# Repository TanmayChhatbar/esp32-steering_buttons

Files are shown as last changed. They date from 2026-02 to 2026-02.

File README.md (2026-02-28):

# ESP32 Steering Buttons

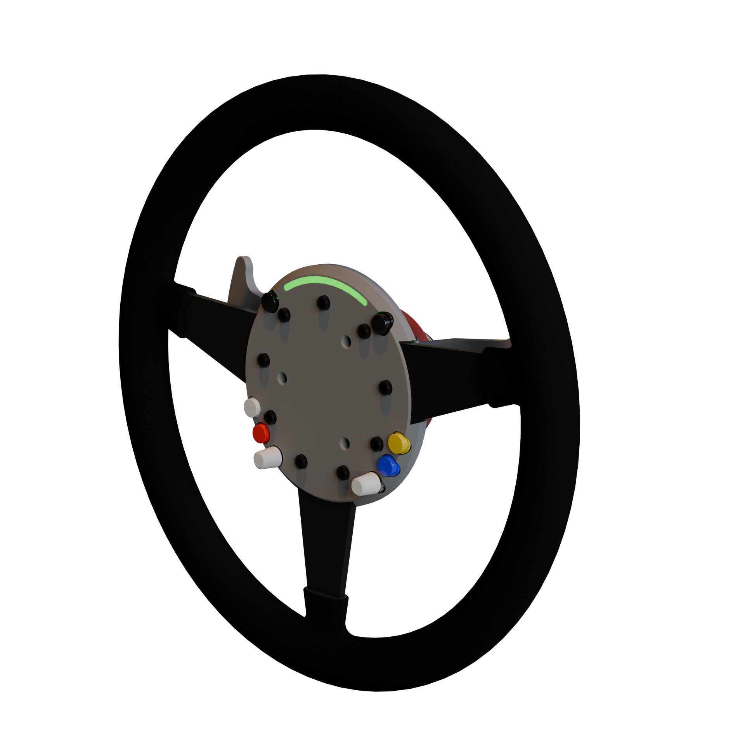
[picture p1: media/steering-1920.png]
Demo Video


## What you will need

- A steering wheel
- A few buttons
- A few encoders
- ESP32-S3 Supermini
- Simagic QR70 Quick-release (I use this for powering the ESP32 on the board)

## Notes

This repository is more a demo than a guide for DIY wheel buttons for an ESP32.

It uses the lemmingdev/ESP32-BLE-Gamepad library to handle the joystick control component.

LED is WIP.

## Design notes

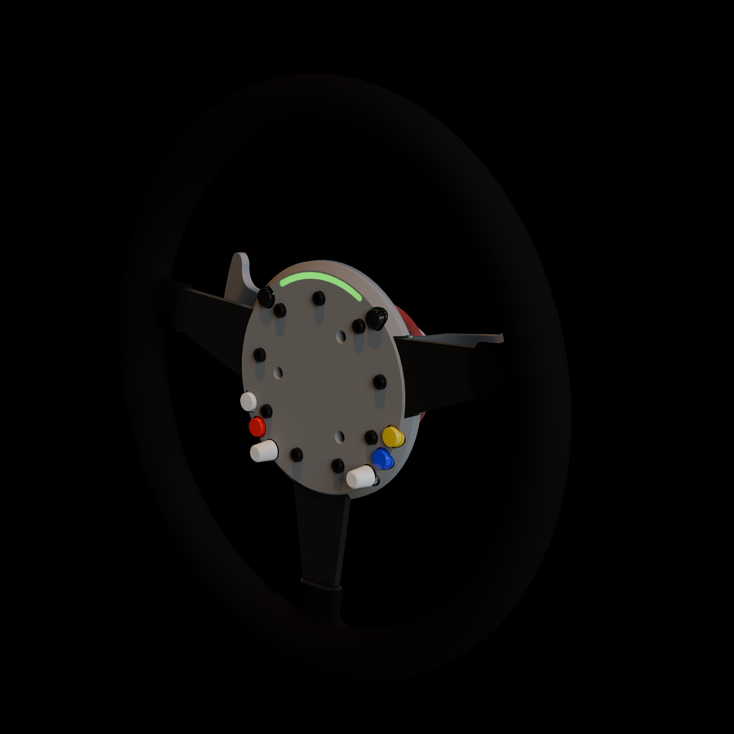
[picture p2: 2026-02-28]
media/steering.jpg

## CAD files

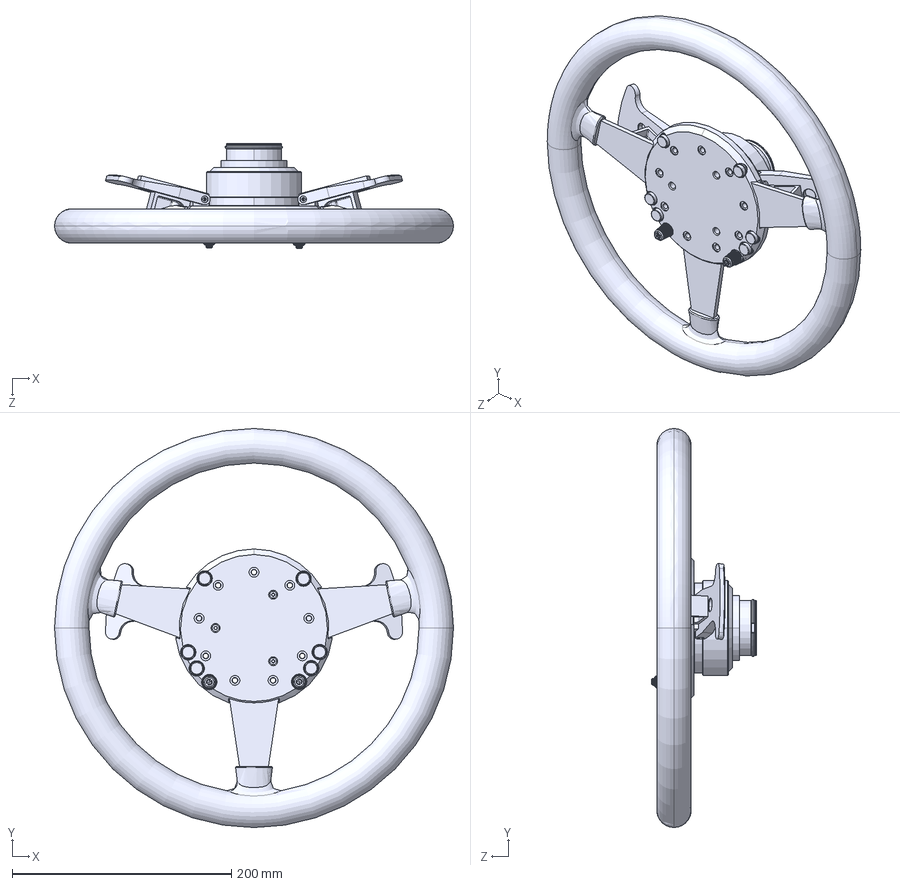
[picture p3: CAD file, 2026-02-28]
CAD/assembly-steering.STEP
363.6 x 363.6 x 96.1 mm
QR70_Retracted
steering_adapter
steering_wheel
paddle
paddle button x 2
Mirrorpaddle
button x 6
enc_knob x 2
steering face cover
TL1100F160Q--3DModel-STEP-520916.step x 6
D2FC_F_7N_20M_BUTTON.step x 2
D2FC_F_7N_20M_BASE.step x 2
ACZ11BR1E-20KQD1-20C.step x 2
LED_WS2812B_PLCC4_5.0x5.0mm_P3.2mm.step x 10
SW_Push_SPST_NO_Alps_SKRK.step x 4
JST_XH_S2B-XH-A-1_1x02_P2.50mm_Horizontal.step
esp32-steering_PCB.step

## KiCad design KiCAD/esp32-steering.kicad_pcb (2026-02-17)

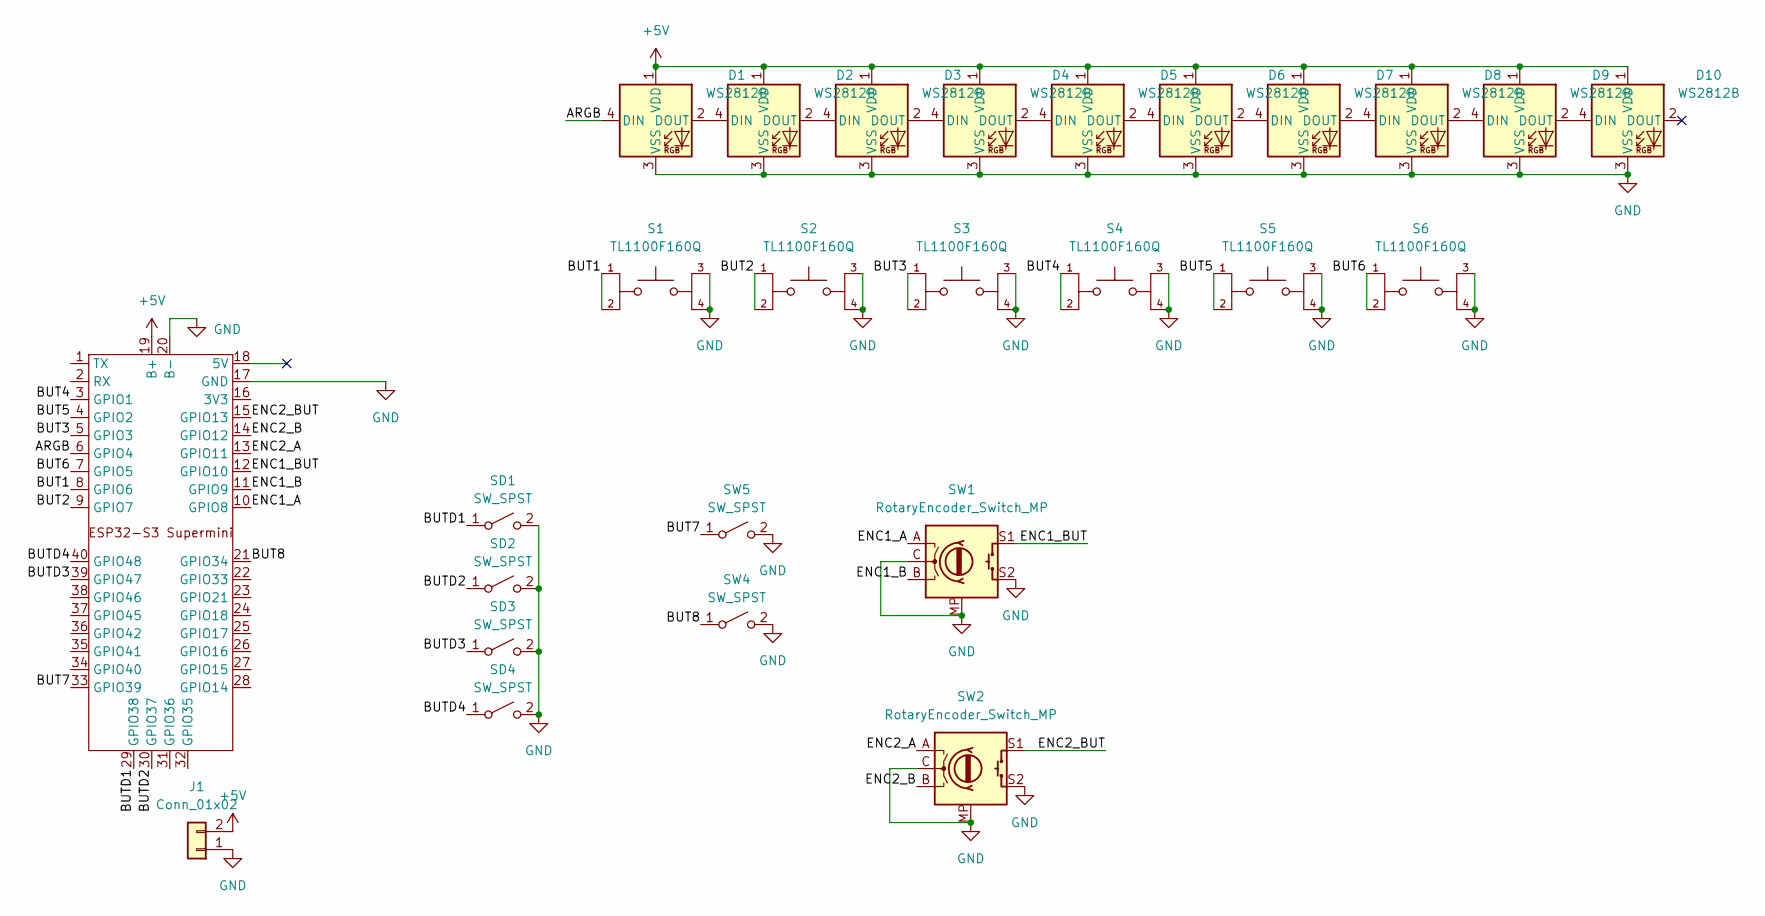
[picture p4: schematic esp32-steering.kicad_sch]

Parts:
D1, D2, D3, D4, D5, D6, D7, D8, D9, D10: WS2812B; LED_WS2812B_PLCC4_5.0x5.0mm_P3.2mm
J1: Conn_01x02; JST_XH_S2B-XH-A-1_1x02_P2.50mm_Horizontal-short
S1, S2, S3, S4, S5, S6: TL1100F160Q; SW_TL1100F160Q; PARTREV D
SD1, SD2, SD3, SD4: SW_SPST; SW_Push_SPST_NO_Alps_SKRK
SW1, SW2: RotaryEncoder_Switch_MP; RotaryEncoder_Alps_EC11E-Switch_Vertical_H20mm_MountingHoles
SW4, SW5: SW_SPST; SW_D2FC_OMR
U1: ESP32-S3 Supermini

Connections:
+5V: D1.1 (VDD), D2.1 (VDD), D3.1 (VDD), D4.1 (VDD), D5.1 (VDD), D6.1 (VDD), D7.1 (VDD), D8.1 (VDD), D9.1 (VDD), D10.1 (VDD), J1.2, U1.19 (B+)
/ARGB: D1.4 (DIN), U1.6 (GPIO4)
/BUT1: S1.1, S1.2, U1.8 (GPIO6)
/BUT2: S2.1, S2.2, U1.9 (GPIO7)
/BUT3: S3.1, S3.2, U1.5 (GPIO3)
/BUT4: S4.1, S4.2, U1.3 (GPIO1)
/BUT5: S5.1, S5.2, U1.4 (GPIO2)
/BUT6: S6.1, S6.2, U1.7 (GPIO5)
/BUT7: SW5.1 (A), U1.33 (GPIO39)
/BUT8: SW4.1 (A), U1.21 (GPIO34)
/BUTD1: SD1.1 (A), U1.29 (GPIO38)
/BUTD2: SD2.1 (A), U1.30 (GPIO37)
/BUTD3: SD3.1 (A), U1.39 (GPIO47)
/BUTD4: SD4.1 (A), U1.40 (GPIO48)
/ENC1_A: SW1.A, U1.10 (GPIO8)
/ENC1_B: SW1.B, U1.11 (GPIO9)
/ENC1_BUT: SW1.S1, U1.12 (GPIO10)
/ENC2_A: SW2.A, U1.13 (GPIO11)
/ENC2_B: SW2.B, U1.14 (GPIO12)
/ENC2_BUT: SW2.S1, U1.15 (GPIO13)
GND: D1.3 (VSS), D2.3 (VSS), D3.3 (VSS), D4.3 (VSS), D5.3 (VSS), D6.3 (VSS), D7.3 (VSS), D8.3 (VSS), D9.3 (VSS), D10.3 (VSS), J1.1, S1.3, S1.4, S2.3, S2.4, S3.3, S3.4, S4.3, S4.4, S5.3, S5.4, S6.3, S6.4, SD1.2 (B), SD2.2 (B), SD3.2 (B), SD4.2 (B), SW1.C, SW1.MP, SW1.S2, SW2.C, SW2.MP, SW2.S2, SW4.2 (B), SW5.2 (B), U1.17 (GND), U1.20 (B-)
unnamed: D1.2 (DOUT), D2.4 (DIN)
unnamed: D2.2 (DOUT), D3.4 (DIN)
unnamed: D3.2 (DOUT), D4.4 (DIN)
unnamed: D4.2 (DOUT), D5.4 (DIN)
unnamed: D5.2 (DOUT), D6.4 (DIN)
unnamed: D6.2 (DOUT), D7.4 (DIN)
unnamed: D7.2 (DOUT), D8.4 (DIN)
unnamed: D8.2 (DOUT), D9.4 (DIN)
unnamed: D9.2 (DOUT), D10.4 (DIN)

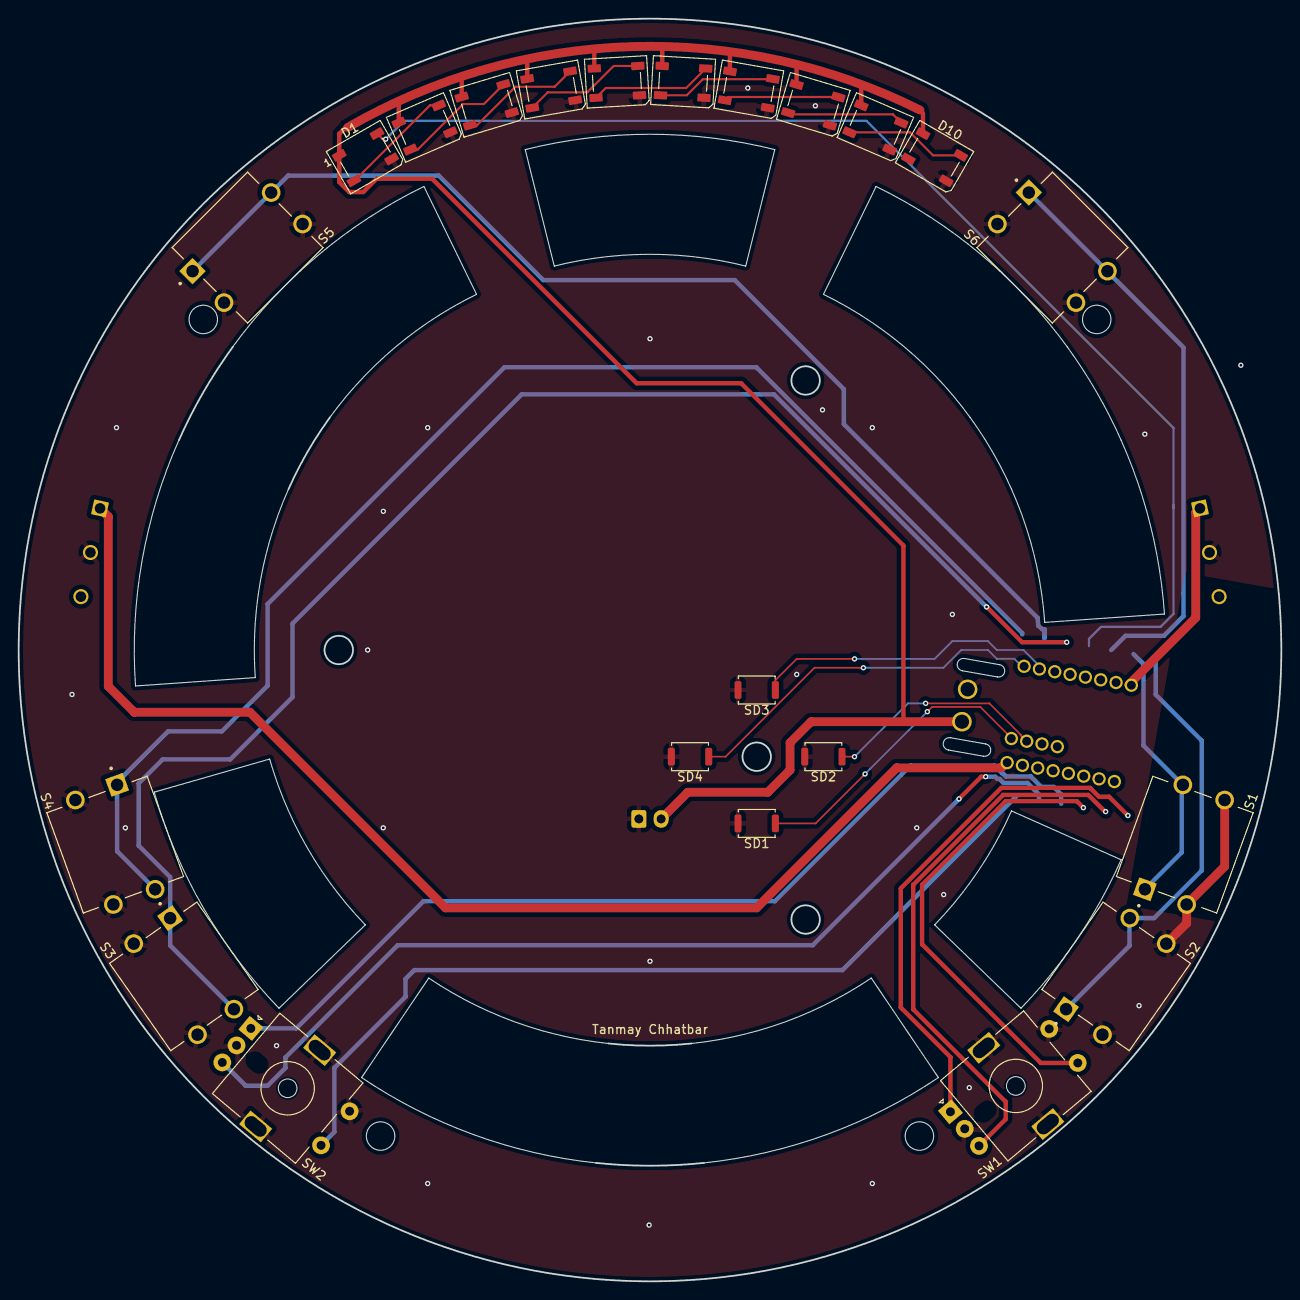
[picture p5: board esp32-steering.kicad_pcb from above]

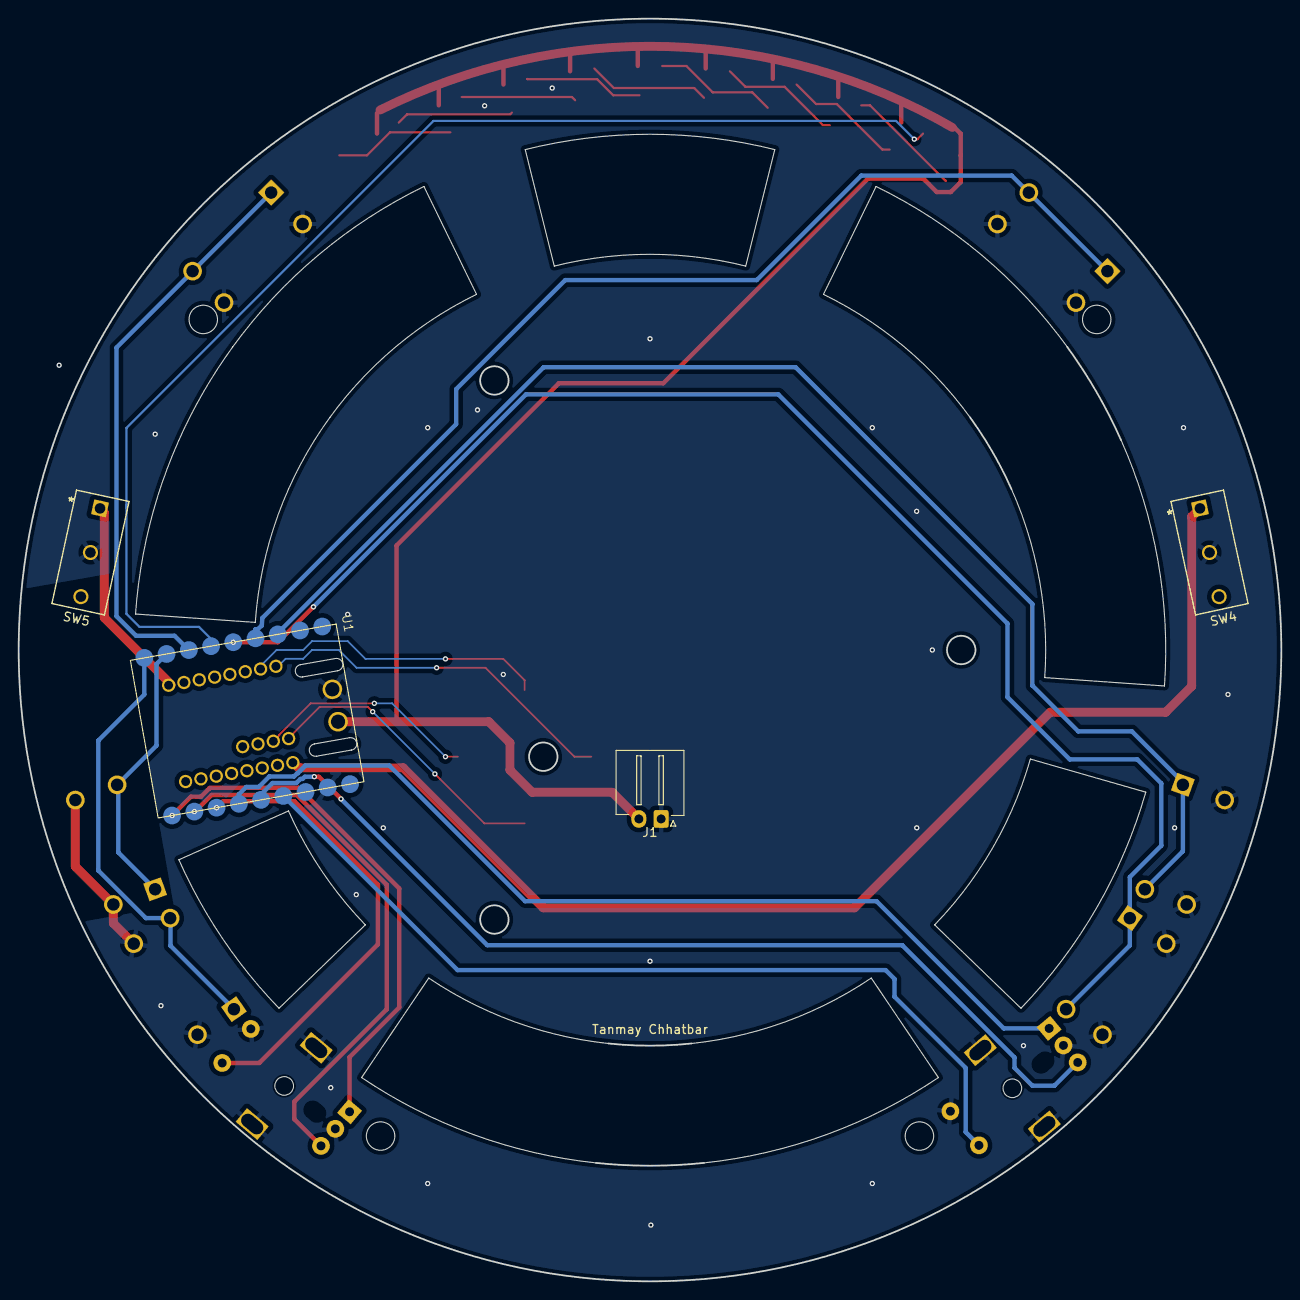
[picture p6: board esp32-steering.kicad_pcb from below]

Board: 2 copper layers, 142.0 x 142.0 mm, 26 parts (4 on the bottom side), 30 nets.

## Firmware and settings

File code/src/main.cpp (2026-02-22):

#include <Arduino.h>
#include <BleGamepad.h> // https://github.com/lemmingDev/ESP32-BLE-Gamepad
#define ENCODER_DO_NOT_USE_INTERRUPTS
#include <Encoder.h>
#include <WiFi.h>
#include <ArduinoOTA.h>
#include "credentials.h"
BleGamepad bleGamepad;

// normal buttons
#define NUM_BUTTONS (1 + 8 + 4 + 2)
const int pins[] = {
    6, 6, 7, 3, 1, 2, 5, 39, 34, // BUT* (first is dummy because windows doesnt report this, it seems)
    38, 37, 47, 48,              // BUTD*
    10, 13                       // ENC1, ENC2
};

// encoders
#define NUM_ENC 2
const int encPins[] = {
    14, 9, // ENC1 was originally 8, 9, 10 according to design, but i burnt the solder pad
    11, 12 // ENC2
};
Encoder enc[NUM_ENC] = {
    Encoder(encPins[0], encPins[1]),
    Encoder(encPins[2], encPins[3])};
int previousEncoderPositions[NUM_ENC] = {
    0, 0};
int currentEncoderPositions[NUM_ENC] = {
    0, 0};

// init arrays
bool previousButtonStates[NUM_BUTTONS + NUM_ENC * 2];
bool currentButtonStates[NUM_BUTTONS + NUM_ENC * 2];

// init timers
unsigned long lastReportTime = 0;
unsigned long lastEncoderChangeTime = 0;
bool encoderChangeReported = 0;

// OTA
bool OTAMode = false;

void initButtonPins()
{
    for (int i = 0; i < NUM_BUTTONS; i++)
    {
        pinMode(pins[i], INPUT_PULLUP);
        previousButtonStates[i] = HIGH;
        currentButtonStates[i] = HIGH;
    }

    // init enc pins
    for (int i = 0; i < NUM_ENC * 2; i++)
    {
        pinMode(encPins[i], INPUT_PULLUP);
        previousButtonStates[NUM_BUTTONS + i] = HIGH;
        currentButtonStates[NUM_BUTTONS + i] = HIGH;
    }
}

void setup()
{
    Serial.begin(115200);

    // init button pins
    initButtonPins();

    if (!digitalRead(pins[7]) && !digitalRead(pins[8]))
    {
        WiFi.begin(ssid, password);
        while (WiFi.waitForConnectResult() != WL_CONNECTED)
        {
            delay(5000);
            ESP.restart();
        }
        Serial.println("OTA Mode");
        Serial.print("IP Address: ");
        Serial.println(WiFi.localIP());
        ArduinoOTA.begin(); // Starts OTA
        OTAMode = true;
    }
    else
    {
        // init gamepad
        BleGamepadConfiguration bleGamepadConfig;
        bleGamepadConfig.setAutoReport(false);
        bleGamepadConfig.setButtonCount(NUM_BUTTONS + NUM_ENC * 2);
        bleGamepad.begin(&bleGamepadConfig);
    }
}

void updateButtonStatus()
{
    for (int i = 0; i < NUM_BUTTONS; i++)
    {
        currentButtonStates[i] = digitalRead(pins[i]);

        if (currentButtonStates[i] != previousButtonStates[i])
        {
            if (currentButtonStates[i] == LOW)
            {
                bleGamepad.press(i);
                Serial.println("Pressed button " + String(i));
            }
            else
            {
                bleGamepad.release(i);
                Serial.println("Released button " + String(i));
            }
        }

        previousButtonStates[i] = currentButtonStates[i];
    }
}

void updateEncoderStatus()
{
    for (int i = 0; i < NUM_ENC; i++)
    {
        currentEncoderPositions[i] = enc[i].read() / 4;
    }
    if (millis() - lastEncoderChangeTime > 20)
    {
        for (int i = 0; i < NUM_ENC; i++)
        {
            if (currentEncoderPositions[i] > previousEncoderPositions[i])
            {
                // if position increased
                bleGamepad.press(NUM_BUTTONS + i * 2);
                previousEncoderPositions[i] = currentEncoderPositions[i];
                encoderChangeReported = 0;
                Serial.println("Encoder " + String(i) + " increased to " + String(currentEncoderPositions[i]));
            }
            else if (currentEncoderPositions[i] < previousEncoderPositions[i])
            {
                // if position decreased
                bleGamepad.press(NUM_BUTTONS + i * 2 + 1);
                previousEncoderPositions[i] = currentEncoderPositions[i];
                encoderChangeReported = 0;
                Serial.println("Encoder " + String(i) + " decreased to " + String(currentEncoderPositions[i]));
            }
            else if (encoderChangeReported)
            {
                // if position hasnt changed and last position was registered
                if (bleGamepad.isPressed(NUM_BUTTONS + i * 2))
                {
                    bleGamepad.release(NUM_BUTTONS + i * 2);
                    Serial.println("Encoder " + String(i) + " released");
                }
                if (bleGamepad.isPressed(NUM_BUTTONS + i * 2 + 1))
                {
                    bleGamepad.release(NUM_BUTTONS + i * 2 + 1);
                    Serial.println("Encoder " + String(i) + " released");
                }
            }
            previousEncoderPositions[i] = currentEncoderPositions[i];
            lastEncoderChangeTime = millis();
        }
    }
}

void loop()
{
    if (OTAMode)
    {
        ArduinoOTA.handle();
    }
    else
    {
        if (bleGamepad.isConnected())
        {
            if (millis() - lastReportTime > 20)
            {
                lastReportTime = millis();
                encoderChangeReported = 1;
                updateButtonStatus();
            }
            bleGamepad.sendReport();
        }
        updateEncoderStatus(); // out of the loop to keep quicker updates
    }
}

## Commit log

2026-02-04 kicad files - export version
    [esp32-steering.kicad_pcb, esp32-steering.kicad_sch]
2026-02-17 correct footprint and pcb design for battery connections
    [esp32-steering.kicad_pcb, esp32-steering.kicad_sch]
2026-02-17 basic button test works
2026-02-18 shift encoder buttons to prevent clash
    [main.cpp]
2026-02-28 add CAD, mp4 and readme
    [assembly-steering.STEP]
2026-11-03 led test works
2026-11-03 led works for assetto corsa
2026-11-03 smooth transition for leds
2026-11-04 three modes for leds, asymmetric, symmetric, and all-same
2026-11-05 led focused on higher rpm
2026-11-11 LED works. update readme
